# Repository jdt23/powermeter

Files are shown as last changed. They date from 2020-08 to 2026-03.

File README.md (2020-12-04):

# powerMeter
This project is a power meter for a bike that computes power, cadence, and resistance similar to a peloton bike.  For those of us who just have simple exercise bikes and a peloton digital subscription, this helps provide objective numbers to match to the instructors' cadence and resistance measurements.

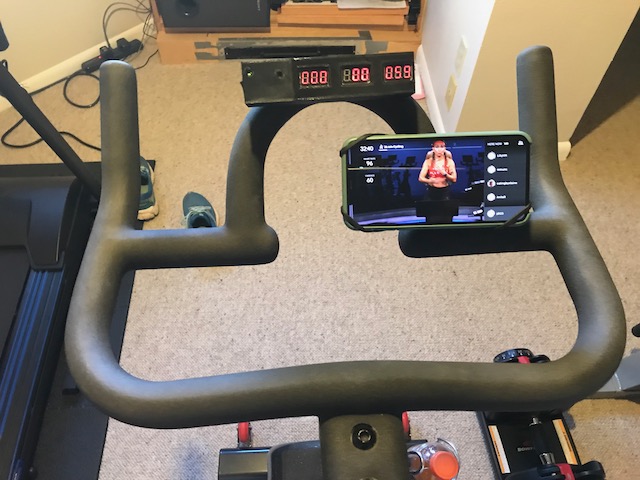
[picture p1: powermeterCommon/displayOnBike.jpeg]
display mounted on the bike handle bars

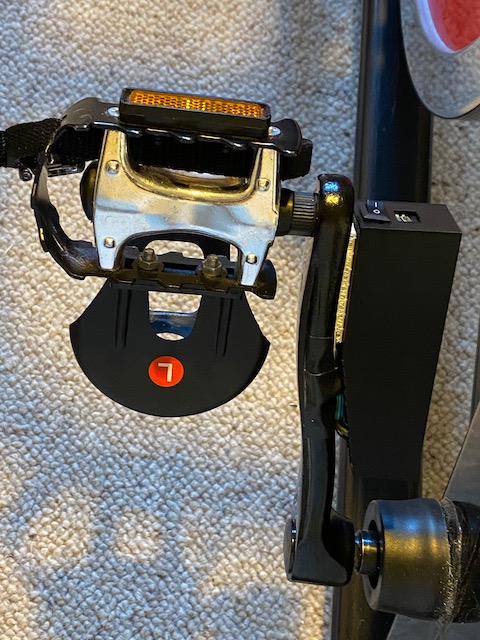
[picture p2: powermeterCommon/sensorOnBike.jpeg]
sensor mounted on bike crank


The solution I came up here uses a sensor unit attached to your bike crank, along with a display unit you attach to your handlebars.  The two units both use the [Arduino Nano 33 BLE](https://store.arduino.cc/usa/nano-33-ble) microprocessor.  For the sensor, the Nano 33 BLE is nice because it is tiny, it has an integrated IMU to give you a gyroscope for cadence, it has enough pins to interface with the force sensors, and it uses low power bluetooth 5.0.  For the display, it gets tight but has just enough GPIO ports for the cheap 7-segment LEDs I chose, and of course has bluetooth 5.0 to recieve the data from the sensor.  For powering both, I use 4x AAA rechargable batteries.

I also 3D-printed the cases for the sensor and display.

## powermeterSensor
This is the thing you attach to the bike crank. The key sensor here is the [HX711](https://smile.amazon.com/gp/product/B07MTYT95R) configured in a [wheatstone bridge](powermeterCommon/HX711_circuit.jpg).

### Algorithm
```
void setup() {
    set up bluetooth characteristics for read, notify
}
void loop() {
    read sensors
    compute new values
    if values change,
        write to bluetooth characteristics
}
```

### Power

Power meters measure the amount of force you exert on the bike crank.  This uses a strain gauge, similar to what is in a typical weight scale.  For some more background, take a look at [this student project](https://digitalcommons.calpoly.edu/cgi/viewcontent.cgi?article=1292&context=cpesp), which helped me get started.

#### Strain gauges

When a strain gauge is stressed, the resistance changes.  You can read the voltage across that resistor to detect the amount of change.  The problem is that this is a very noisy system, so people typically use a [Wheatstone Bridge](https://en.wikipedia.org/wiki/Wheatstone_bridge) circuit.

Wheatstone Bridge

In a Wheatstone Bridge such as the one in the figure above, you can apply a known voltage across A and C, then measure the output voltage across B and D.  If you apply 4 strain gauges on the bike crank in the right places, you can get it so an increase in resistance in R1 will also result in a reduction in resistance in R2, amplifying the change while introducing some redundancy (which is good).

I attached the strain gauges to bike crank with a very thin layer of superglue.

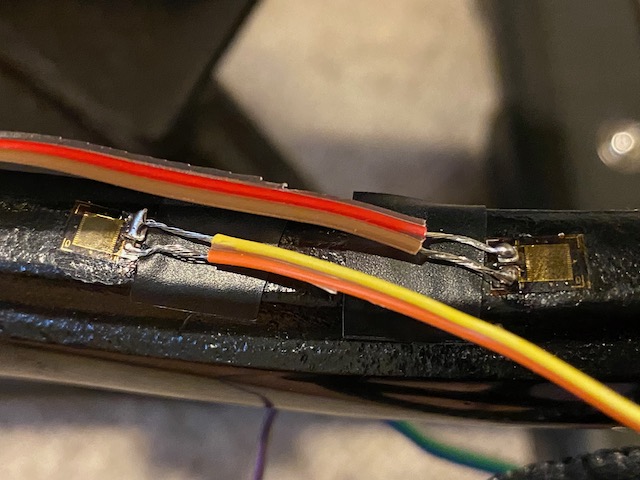
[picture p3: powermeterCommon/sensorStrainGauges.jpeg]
strain gauges


Using a bunch of electrical tape, I covered up all the wires and sensors on the bike crank, which ended up looking fairly clean.

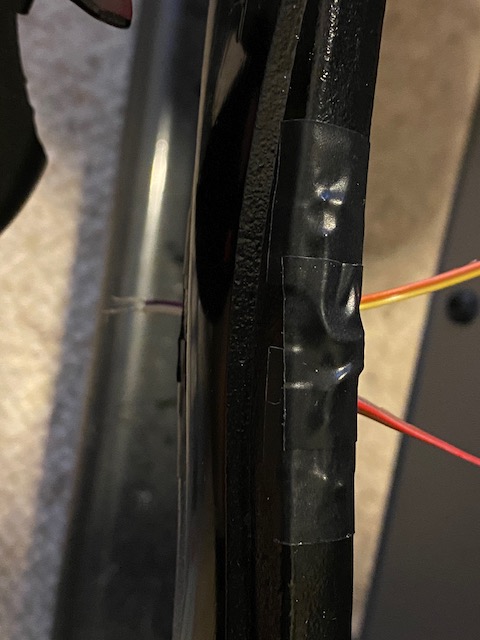
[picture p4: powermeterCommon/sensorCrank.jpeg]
bike crank


#### Amplifier

The resistance change from the strain gauges is still very small, so we need to amplify it.  To do that, most people use an [HX711](https://cdn.sparkfun.com/datasheets/Sensors/ForceFlex/hx711_english.pdf) circuit such as the one below.

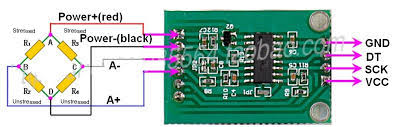
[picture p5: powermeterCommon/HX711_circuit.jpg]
hx711 image


This circuit is fairly easy to use, cheap, and has a well supported [library](https://github.com/bogde/HX711) to simplify usage.

#### Computing Force

The instantaneous power of an angularly accelerating body is the torque (tau) times the angular velocity (omega).



Tau is just Force x Distance, so we get:



We'll get the force from the HX711, after calibrating and scaling.  r is the radius of the bike crank.  Angular velocity here is expected in radians/second, and the Arduino gives it to you in degrees/second, so we have to remember to multiply by a scale factor.  2pi radians is 360 degrees, so you multiply your dps by pi/180



Done.  

I skipped over calibrating and scaling the readings off the HX711, but it's relatively straightforward.  I assume zero weight when turning on the sensor, and use the first few seconds to read the neutral scale reading. That becomes the offset you pass to the `scale.set_offset()` function.  Then, I put a known weight (5 lbs in my case) on the pedal, and read the scale.  Each pound is 4.448 Newtons, so I set the scale factor to the reading divided by the weight I used times 4.448



### Resistance

Now this is the hard part.  Peloton listed official (Power,Resistance,Cadence) triples [here](https://www.reddit.com/r/pelotoncycle/wiki/index/faq/bikecalibration).  A nice user put those datapoints into a regression script and came up with equations [here](https://www.reddit.com/r/pelotoncycle/comments/gwpyfw/diy_peloton_resistance_output/):

![](https://latex.codecogs.com/svg.latex?\Large&space;r=145\left(\frac{Power}{11.29(Cadence-22.5)^{1.25}}\right)^{0.4651})

I plotted the sample points and verified the equations seem to work in [this script](./powermeterCommon/calibrate.py).

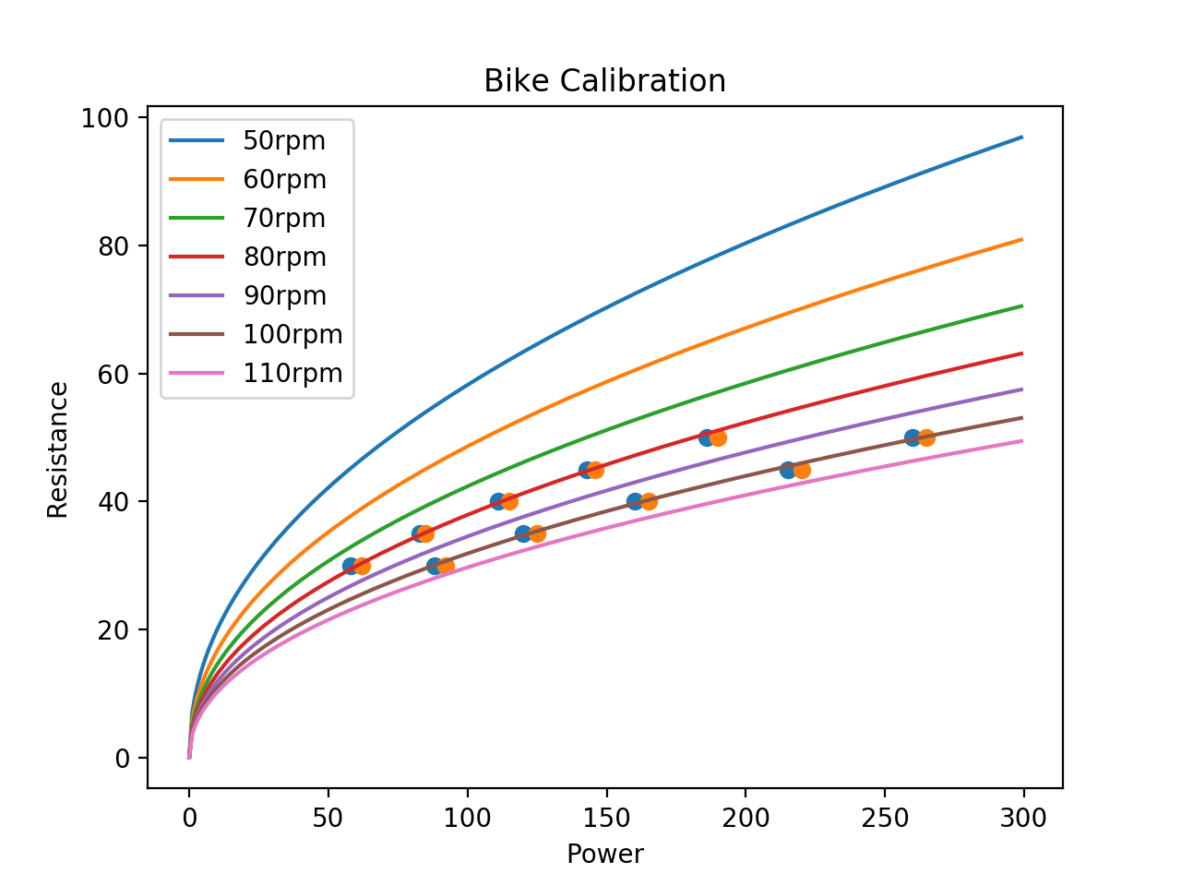
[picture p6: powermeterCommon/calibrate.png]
plot of known datapoints and equations


So I just plugged in those equations, fixed up for cases where it would fall below zero and produce NaNs, and boom, done.

### Cadence

Cadence is easily sensed using the IMU on the Nano 33 BLE.  There's a simple `readGyroscope()` API.  You grab the z direction of that, and convert from degrees per second to revolutions per minute.

In full disclosure, I had to multiply the cadence by (7/6) for some reason I haven't figured out yet.  Doing this, I exactly match the wahoo cadence sensor I already had.  Some day I should try to fix this, but if you know why I might be off by 7/6, please let me know.

### Power supply

A key requirement is to have a power supply that is cabable of providing sustained current.  I initially started with some button batteries, but those would only last about 10 minutes before they started giving bogus numbers as a result of insufficient voltage to the chip.  Because of that, I moved to using 4xAAA rechargeable batteries.  This makes the cases slightly larger, but I believe they're still reasonably sized.

### Measurements

Any measurement is going to have some noise to it.  To add some hysteresis, I created a `Measurement` struct that can take a `refreshInterval` (in milliseconds) and a way to reduce the results either via averaging or taking the max of a bunch of samples.  

In practice, I settled on about 2 seconds of samples, which ended up being about 20 samples.  For power, I expected to have to use max, but ended up using averaging, similar to cadence and resistance.

### Sensor board and case

For the circuit board, I used a 2cm x 8cm prototype [circuit board](https://smile.amazon.com/gp/product/B072Z7Y19F). That wasn't quite wide enough for the Arduino Nano, so I ended up only using pins on one side of the board, and snipped the headers on the other side so the whole Arduino still laid flat.  I did some clever wiring under the Arduino on the top side of the prototype board, which minimized the wiring underneath.  Next to the Arduino is the HX711, with the input pins soldered to 4 outward facing pins that I would attach the bike to.

Here is the fritzing image of the circuit.

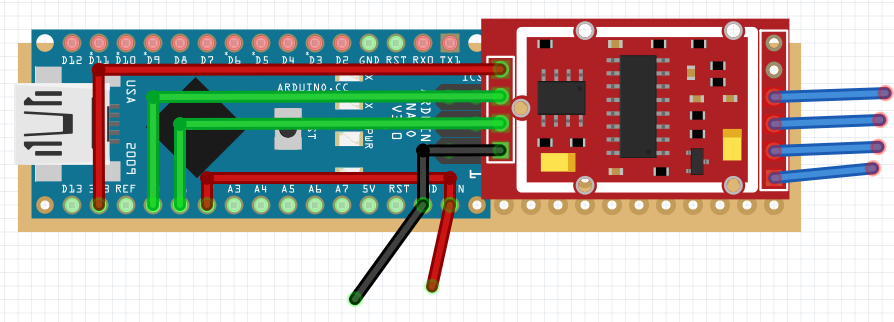
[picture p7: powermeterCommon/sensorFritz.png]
sensor circuit board fritz


And here is the same thing in real life.

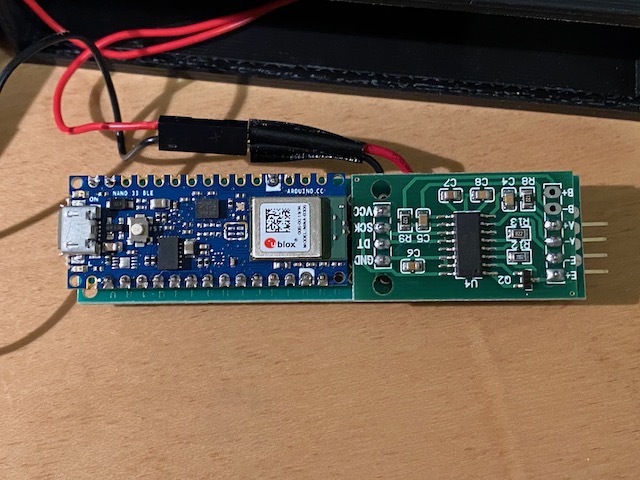
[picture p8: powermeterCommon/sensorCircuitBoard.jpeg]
sensor circuit board


This is a picture of the batteries in the case.

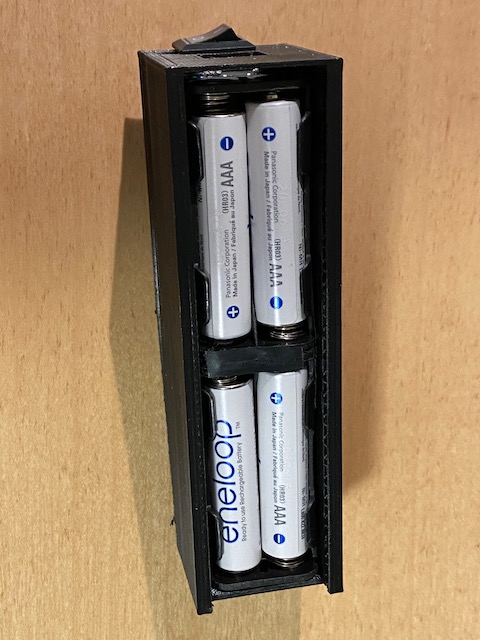
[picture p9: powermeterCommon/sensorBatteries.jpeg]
sensor batteries


And finally, this is the case that I 3D printed for it.

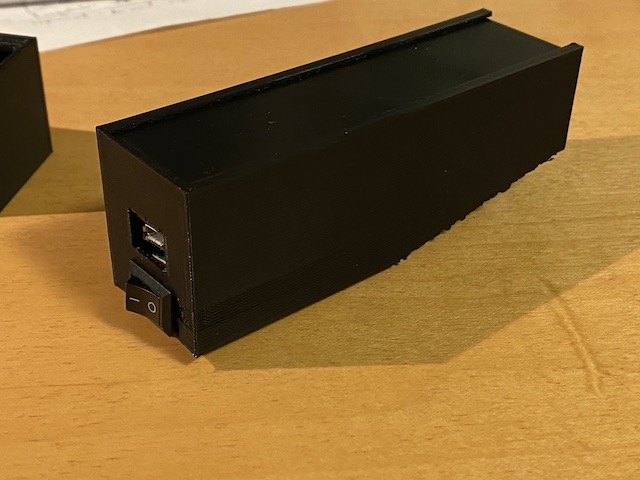
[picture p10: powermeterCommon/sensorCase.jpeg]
sensor case


## powermeterDisplay

You could display the results on your phone, or another type of display.  For my bike, I wanted to play with some seven segment displays, so I got three [three-digit seven segment displays](https://smile.amazon.com/gp/product/B07GTQS4N5).

Pseudo-code is:
```
void setup() {
    set up bluetooth
}

void loop() {
    connect to bluetooth
    while connected to bluetooth{
        subscribe to notifications
        if values updated
            read values
        display
    }
}
```

### 7 segment displays

I bought [cheap 3 digit 7 segment displays](https://smile.amazon.com/gp/product/B07GTQS4N5/) (non-I2C) so it took a lot of the GPIO pins to drive.  This took a lot of wiring.

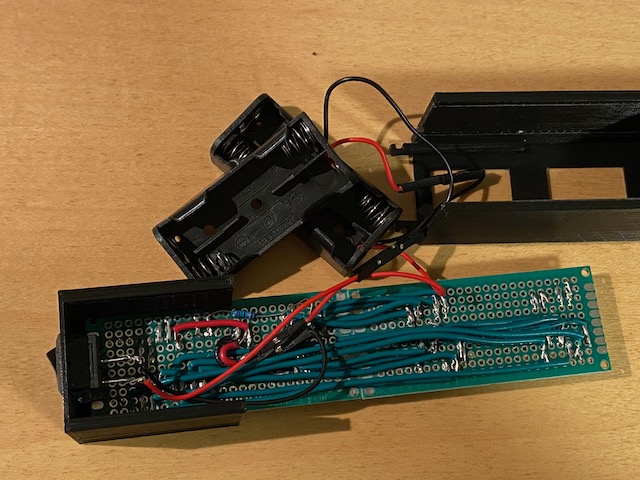
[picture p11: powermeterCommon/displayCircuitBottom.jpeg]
wiring


### Power supply

Just like the sensor, I had some issues with sustained voltage for the display.  I resorted to the same solution for the display, 4x AAA batteries.  For the display, it just extends the height of the case, so it's not a big deal.

### Display Board and Case

For the display, I used two of the 2cm x 8xm prototype boards, taped together.  This perfectly allows room for the Arduino and three 3-digit displays.  The wiring gets tight, but some careful planning solved that.

Here is the circuit board fritz on a much larger PCB.  Converting this to something that all fit in the 2cm x 8cm prototype board took a lot of planning, and using both the top and bottom side of the board.

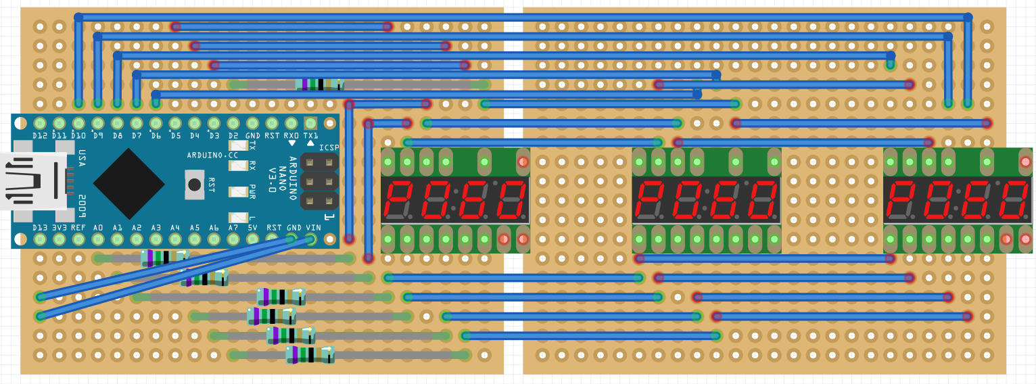
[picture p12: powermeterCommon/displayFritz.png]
display circuit board fritz


And here's a picture of the same thing in real life:

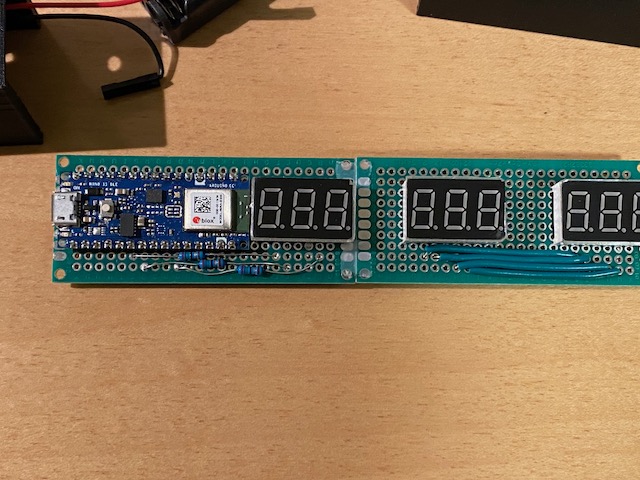
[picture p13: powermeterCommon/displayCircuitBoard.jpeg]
display circuit board


Here's the final case I settled on, after about 10 attempts.

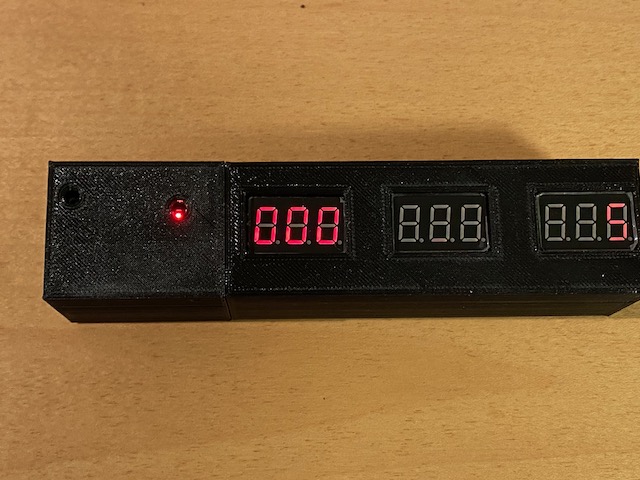
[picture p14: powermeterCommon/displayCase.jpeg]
display case


## Bill of Materials

| Part | Cost Total | Cost for this project |
| ---- | --- | --- |
| [Arduino Nano 33 BLE](https://smile.amazon.com/gp/product/B07WV59YTZ/) | $23.00 each | 2 for $46.00 |
| [LED Displays](https://smile.amazon.com/gp/product/B07GTQS4N5) | $8.59 for 5 | 3 for $5.16 |
| [PCB boards](https://smile.amazon.com/gp/product/B072Z7Y19F) | $9.99 for 32 | 3 for $0.94 |
| [Rocker Switches](https://smile.amazon.com/gp/product/B07JNNXC9N) | $6.99 for 20 | 2 for $0.70 |
| [Battery cases](https://smile.amazon.com/gp/product/B07F3YKGPD) | $4.99 for 6 | 4 for $3.33 |
| [Rechargeable AAA batteries](https://smile.amazon.com/gp/product/B00JHKSMIG) | $16.57 for 8 | 8 for $16.57 |
| [Strain Gauges](https://smile.amazon.com/gp/product/B085W5KSSD) | $4.75 for 10 | 4 for $1.90 |
| [HX711 Load Cell Amplifiers](https://smile.amazon.com/gp/product/B07MTYT95R) | $6.99 for 5 | 1 for $1.40 |
| Total | $104.87 | $76.00 |

Some things, I already had, such as a soldering iron, multimeter, wiring, wire strippers, crimpers, 3d printer with filament, etc, so I'm not including the cost of those.  But for someone new, your upfront costs might be more.

So for $76 plus about $30 of extra parts, I have a power, resistance, and cadence meter.  If I [google for power meters](https://lmgtfy.app/?q=power+meter) alone, the cheapest one I see is about $300, and they get much more expensive than that quickly.  Maybe you already have batteries.

## Future work

I haven't looked at current draw yet.  If the batteries start draining too quickly, I'll have to look at that and likely just sleep longer between sampling and transmitting.

I'd also like to figure out the mysterious (7/6) factor for the cadence.

I could probably also spend more time calibrating the power, but the whole point is that it's an objective measure.  For that, I think the current numbers serve the purpose.

Hope you've enjoyed.  If you end up building something similar, or have any advice, feel free to reach out.

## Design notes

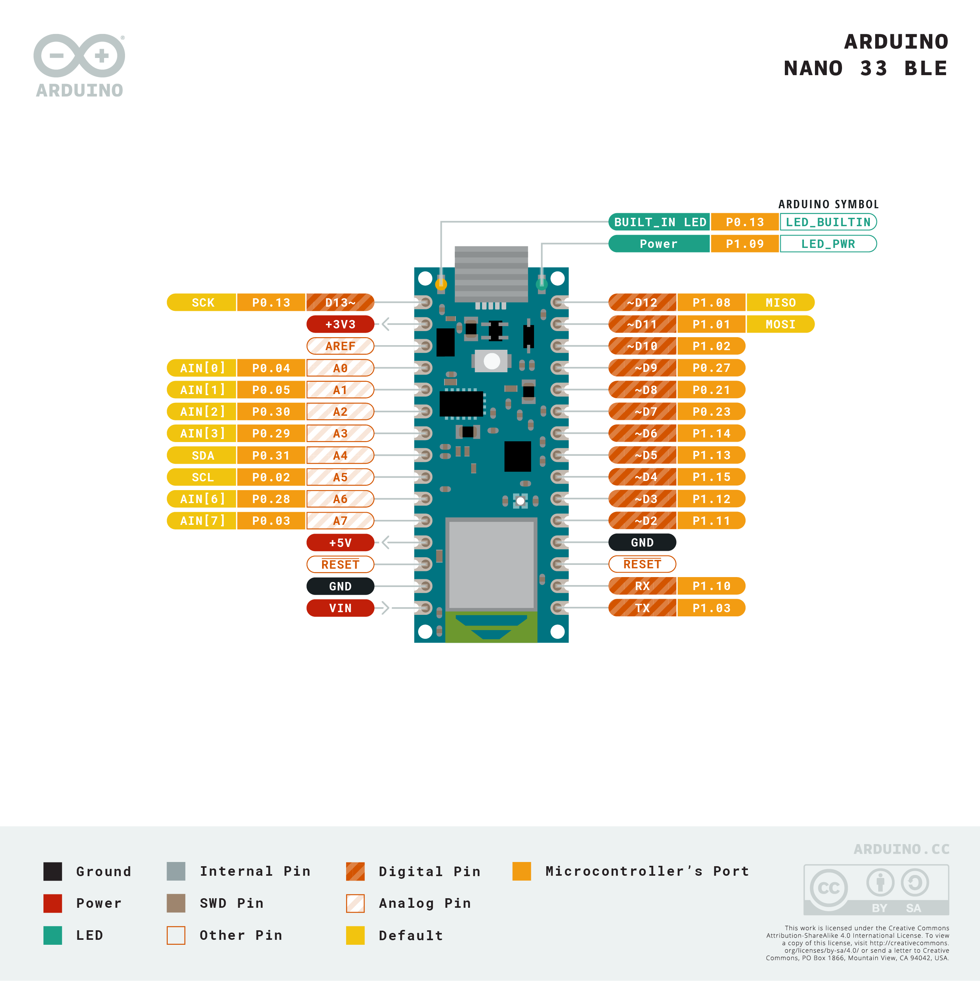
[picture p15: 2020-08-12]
powermeterCommon/nano33ble_pinout.png

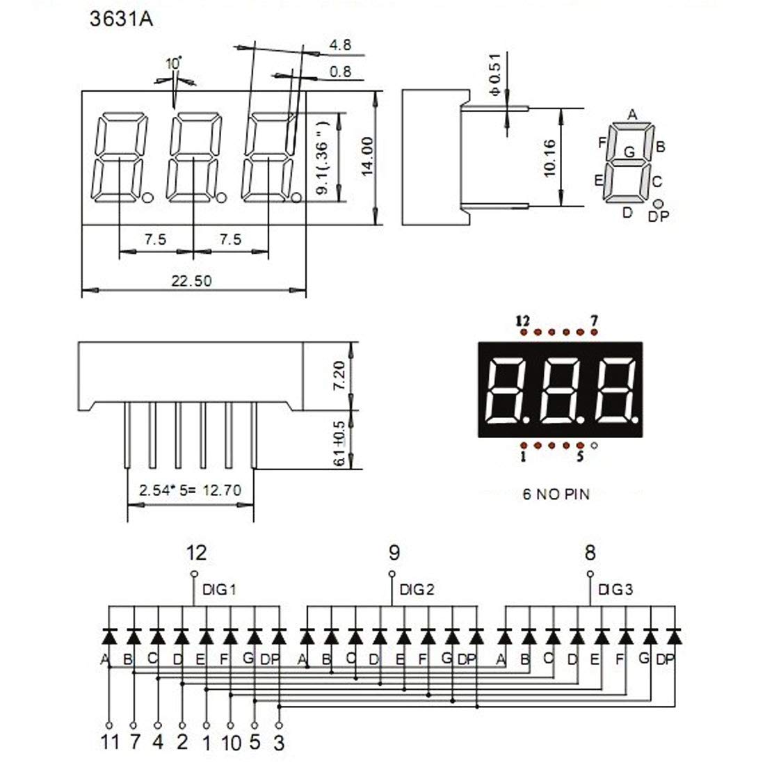
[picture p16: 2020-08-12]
powermeterCommon/3631AH_pins.jpg

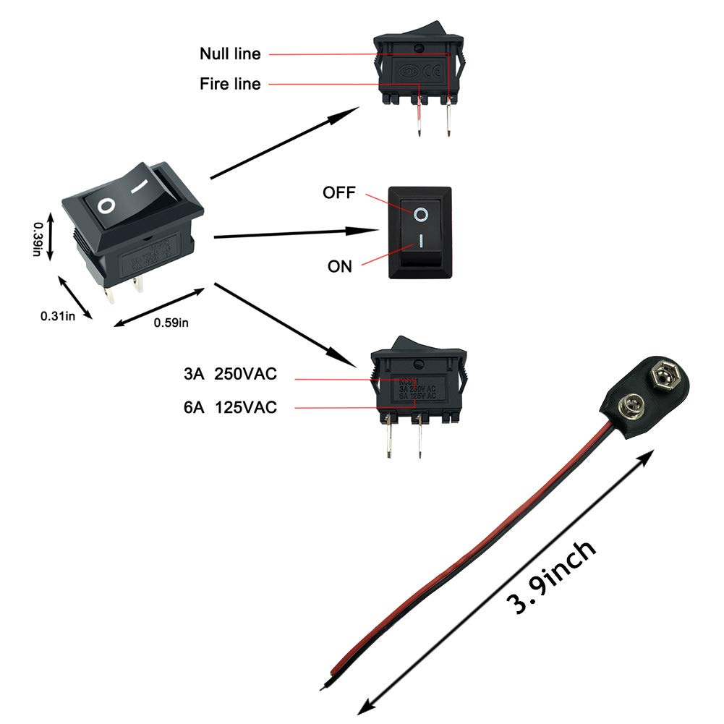
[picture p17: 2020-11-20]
powermeterCommon/rocker_switch.jpg

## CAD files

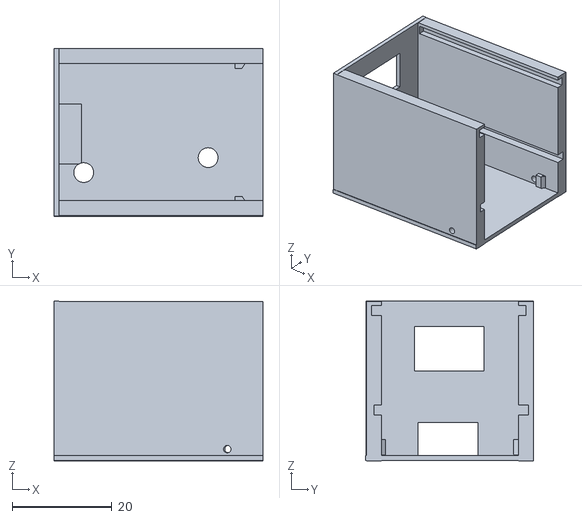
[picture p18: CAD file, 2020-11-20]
powermeterDisplay/case/powermeterDisplay_prototype7_topleft.stl
42.0 x 33.7 x 32.1

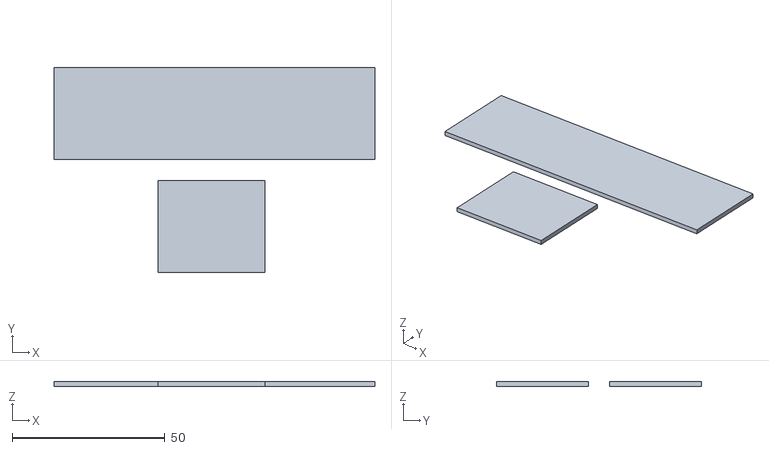
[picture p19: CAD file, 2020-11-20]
powermeterDisplay/case/powermeterDisplay_prototype7_bottoms.stl
105.0 x 67.0 x 1.50

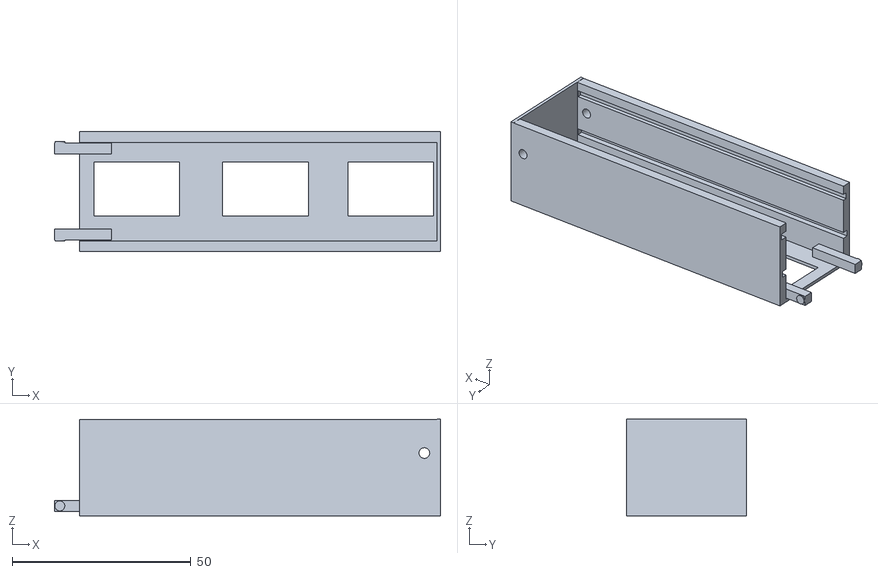
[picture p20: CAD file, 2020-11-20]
powermeterDisplay/case/powermeterDisplay_prototype6_top_right.stl
108.0 x 33.6 x 27.1

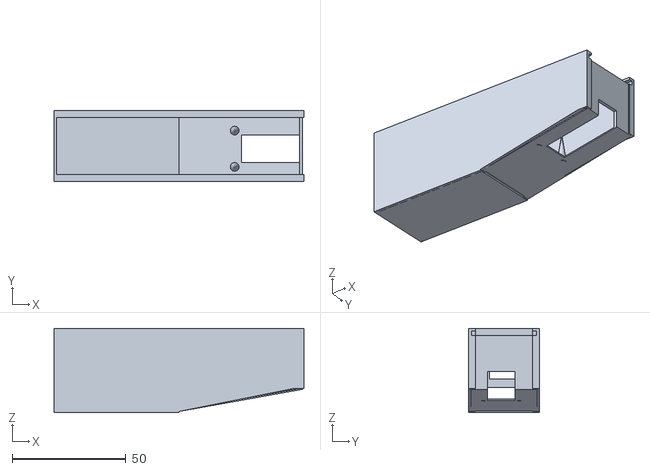
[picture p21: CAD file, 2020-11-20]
powermeterSensor/case/powermeterSensor_prototype4_bottom.stl
110.1 x 31.2 x 37.1

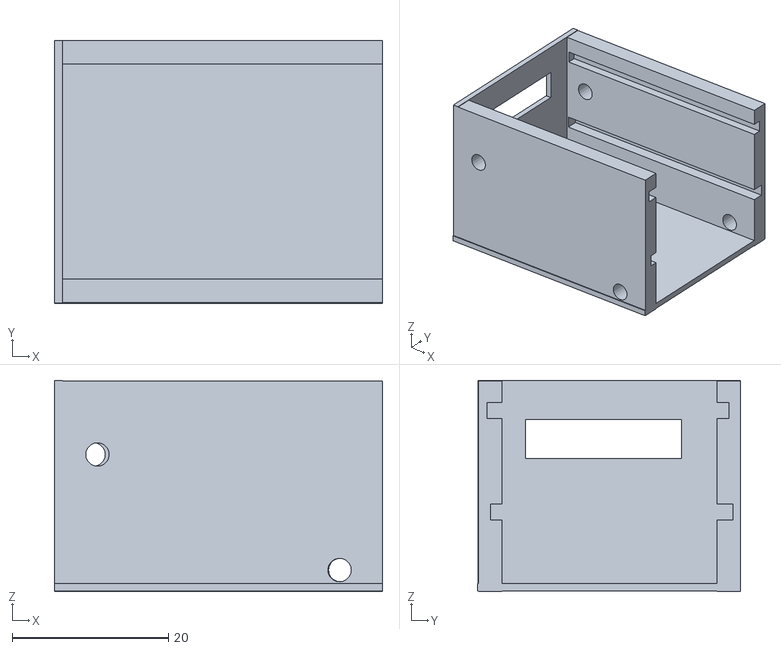
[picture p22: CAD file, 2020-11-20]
powermeterDisplay/case/powermeterDisplay_prototype6_top_left.stl
42.0 x 33.7 x 27.1

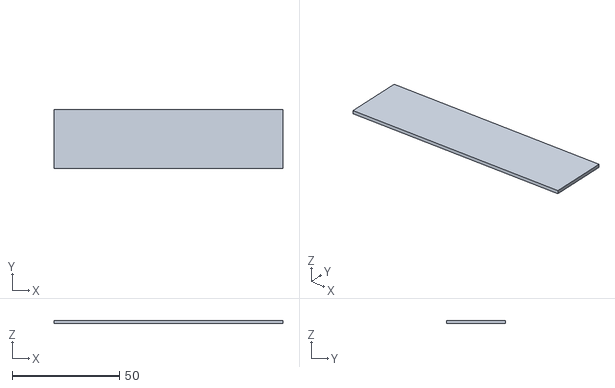
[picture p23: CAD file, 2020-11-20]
powermeterSensor/case/powermeterSensor_prototype4_top.stl
107.0 x 27.5 x 1.50

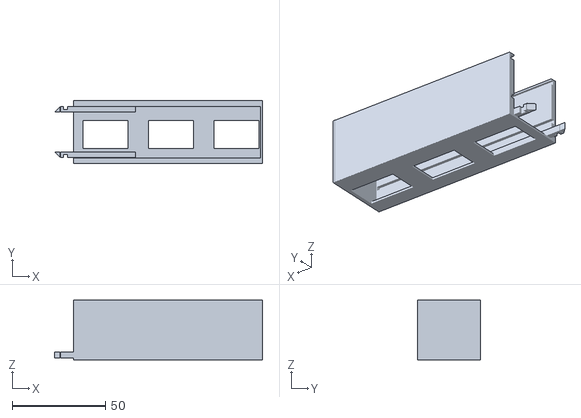
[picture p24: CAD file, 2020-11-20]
powermeterDisplay/case/powermeterDisplay_prototype7_topright.stl
111.3 x 33.6 x 32.1

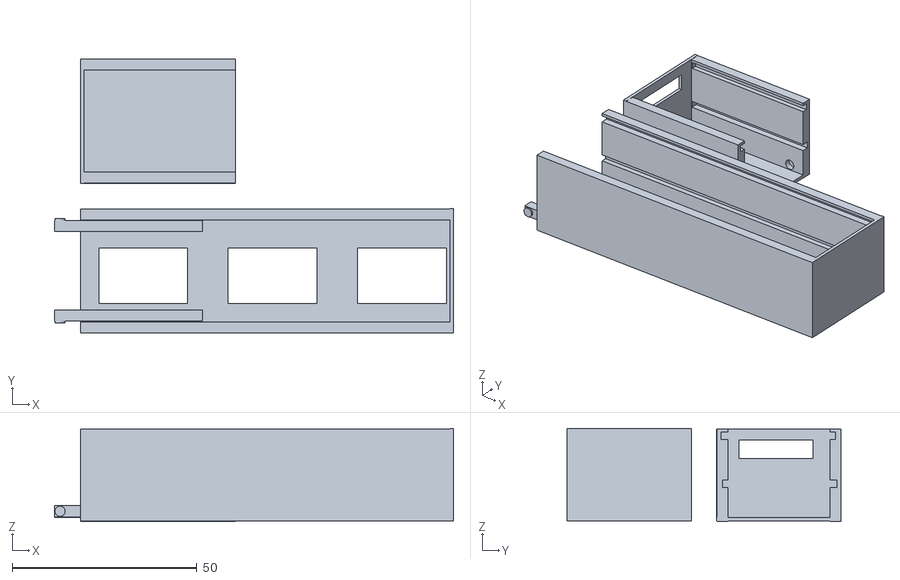
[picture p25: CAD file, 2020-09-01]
powermeterDisplay/case/powermeterDisplay_prototype6_top.stl
108.0 x 74.1 x 25.2

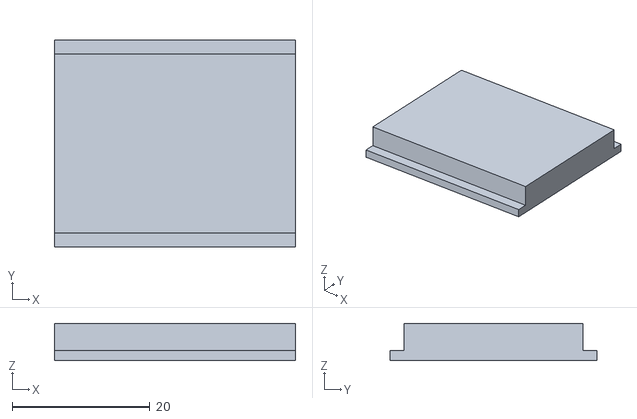
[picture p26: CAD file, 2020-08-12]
powermeterDisplay/case/powermeterDisplay_prototype5_bottomright.stl
35.0 x 30.0 x 5.40

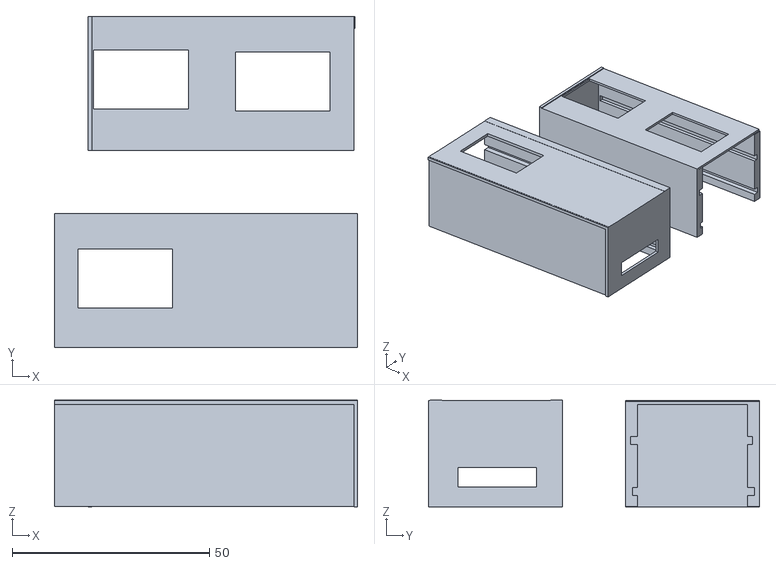
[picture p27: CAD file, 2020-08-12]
powermeterDisplay/case/powermeterDisplay_prototype4_tops.stl
77.0 x 84.0 x 27.1

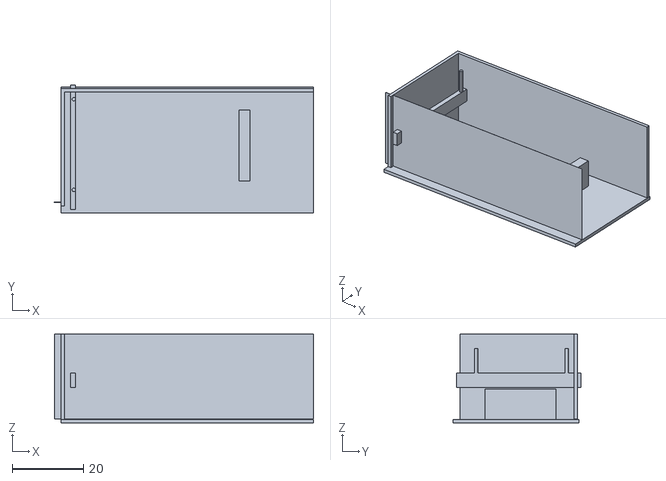
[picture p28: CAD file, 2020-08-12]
powermeterDisplay/case/lefthalf.stl
72.8 x 36.0 x 25.0

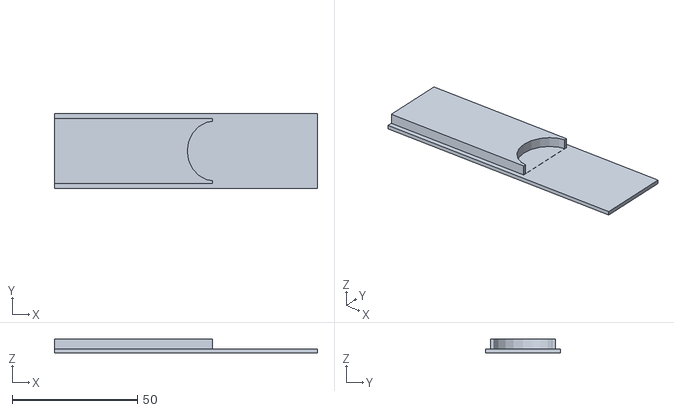
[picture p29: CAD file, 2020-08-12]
powermeterDisplay/case/powermeterDisplay_prototype5_bottomleft.stl
105.0 x 30.0 x 5.40

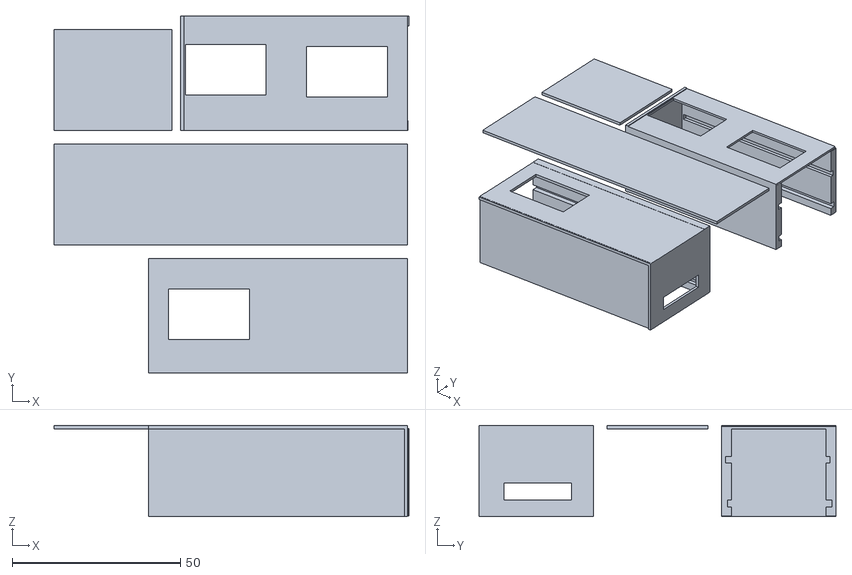
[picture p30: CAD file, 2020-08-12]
powermeterDisplay/case/powermeterDisplay_prototype4.stl
105.4 x 106.0 x 27.1

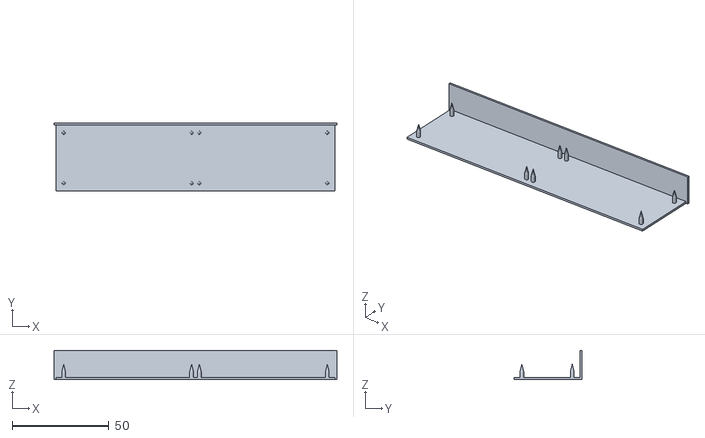
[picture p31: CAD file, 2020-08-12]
powermeterDisplay/case/powermeterPeripheral_LCD.stl
146.0 x 35.0 x 15.0

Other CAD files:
powermeterSensor/case/powermeterSensor_prototype3_bottom.stl
powermeterSensor/case/powermeterSensor_prototype3_top.stl
powermeterSensor/case/powermeterSensor_prototype2_bottom.stl
powermeterSensor/case/powermeterSensor_prototype1_top.stl
powermeterDisplay/case/powermeterDisplay_prototype1.stl
powermeterDisplay/case/powermeterDisplay_prototype2_bottoms.stl
powermeterDisplay/case/powermeterDisplay_prototype2_tops.stl
powermeterDisplay/case/powermeterDisplay_prototype3.stl
powermeterDisplay/case/powermeterDisplay_prototype4_bottoms.stl
powermeterDisplay/case/powermeterDisplay_prototype4_topleft.stl
powermeterDisplay/case/powermeterDisplay_prototype4_topright.stl
powermeterDisplay/case/powermeterDisplay_prototype5_bottoms.stl
powermeterDisplay/case/powermeterDisplay_prototype5_topright.stl
powermeterSensor/case/powermeterSensor_prototype1_bottom.stl
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

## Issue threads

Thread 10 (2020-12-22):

Investigate power consumption

jdt23, 2020-12-22:
Of both the display and the sensor.

One likely culprit is the display - I expect the SevSeg library is refreshing too often.

The sensor is already fairly optimized to not push changes to bluetooth unless needed, so I don't expect much there, but it's definitely possible.

So far, battery life has not been horrible, so not urgent.

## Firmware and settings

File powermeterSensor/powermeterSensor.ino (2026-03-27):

// HX711 Arduino Library - Version: Latest
// For strain gauges
#include <HX711.h>

// ArduinoBLE - Version: Latest
// For bluetooth
#include <ArduinoBLE.h>

BLEService powerMeterService("1818");
// Standard Cycling Power Measurement: 4 bytes (2 flags + 2 power)
BLECharacteristic powerChar("2A63", BLERead | BLENotify, 4);
BLEUnsignedCharCharacteristic  resistanceChar("2AD6", BLERead | BLENotify );
BLEUnsignedCharCharacteristic  cadenceChar("2A5B", BLERead | BLENotify );

// Arduino_LSM9DS1 - Version: Latest
// For IMU
#include <Arduino_LSM9DS1.h>

const float Radius = 0.17; //meters

int counter = 0;

const int DEBUG = 0;

// HX711 circuit wiring
const int LOADCELL_DOUT_PIN = A1;
const int LOADCELL_SCK_PIN = A0;

HX711 scale;
float accelerationSampleRate, gyroscopeSampleRate;

const int BATTERY_PIN = A2;

enum MeasurementMethod {AVERAGE, MAX, NONE};

struct Measurement {
  float accumulator;
  int samples;
  unsigned long last_time;
  unsigned long next_time;
  unsigned int refreshInterval; // in milliseconds
  MeasurementMethod method;

  Measurement(const unsigned int _refreshInterval, MeasurementMethod _method) :
    accumulator(0),
    samples(0),
    last_time(0),
    next_time(0),
    refreshInterval(_refreshInterval),
    method(_method)
    {}
  void reset() {
    accumulator = 0;
    samples = 0;
    last_time = millis();
    next_time = last_time + refreshInterval;
  }
  void addMeasurement(float a) {
    if (method==AVERAGE)
      accumulator += a;
    else if (method == MAX)
      accumulator = fmaxf(a, accumulator);
    samples++;
  }
  bool canGetMeasurement() {
    return (millis() > next_time);
  }
  float getMeasurement() {
    if (DEBUG) {
      Serial.print("accumulator=");
      Serial.print(accumulator);
      Serial.print(" samples=");
      Serial.println(samples);
    }
    if (samples == 0)
      return NAN;
    float retval = NAN;
    if (method==AVERAGE)
      retval= accumulator / samples;
    else if (method==MAX)
      retval = accumulator;
    reset();
    return retval;
  }
};
Measurement powerMeasurement(2000, AVERAGE);
Measurement resistanceMeasurement(2000, AVERAGE);
Measurement cadenceMeasurement(2000, AVERAGE);

void setLED (int r, int g, int b) {
  digitalWrite(LEDR, 1-r);
  digitalWrite(LEDG, 1-g);
  digitalWrite(LEDB, 1-b);
}

void setup() {
  if (DEBUG) Serial.begin(9600);
  //HX711 setup
  scale.begin(LOADCELL_DOUT_PIN, LOADCELL_SCK_PIN);
  //scale.set_offset(1);
  if (DEBUG) Serial.println("Calibrating scale.");
  float offset = scale.get_units(20);
  offset = scale.get_units(10);
  if (DEBUG) Serial.print("Setting offset to ");
  if (DEBUG) Serial.println(offset);
  scale.set_offset(offset);
  //scale.set_offset(136200);
  // 1 pound = 4.4482216153 Newtons
  // scale factor = reading / (N) = reading / (lbs * 4.4482216153)
  //scale.set_scale(1);
  scale.set_scale(5000/ (5 * 4.4482216153));

  // initialize digital pin LED_BUILTIN as an output.
  pinMode(LED_BUILTIN, OUTPUT);
  pinMode(LEDR, OUTPUT);
  pinMode(LEDG, OUTPUT);
  pinMode(LEDB, OUTPUT);

  setLED(0,0,1);

  //IMU setup
  while (!IMU.begin()) {
    if (DEBUG) Serial.println("Failed to initialize IMU!");
    setLED(1,1,0); // yellow
    delay(1000);
  }

  accelerationSampleRate = IMU.accelerationSampleRate();
  gyroscopeSampleRate    = IMU.gyroscopeSampleRate();

  //bluetooth setup
  while ( !BLE.begin() ) {
    if (DEBUG) Serial.println("starting BLE failed!");
    setLED(1,1,1); // white
    delay(1000);
  }
  if (DEBUG) Serial.println ("Bluetooth startup succeeded");

  BLE.setLocalName("powerMeterService");
  BLE.setAdvertisedService(powerMeterService);
  powerMeterService.addCharacteristic(powerChar);
  powerMeterService.addCharacteristic(resistanceChar);
  powerMeterService.addCharacteristic(cadenceChar);
  BLE.addService(powerMeterService);

  BLE.advertise();
  if (DEBUG) Serial.println("Bluetooth device active, waiting for connections...");
}

float computeResistance ( const float &power, const float &rpm ) {

  // https://www.reddit.com/r/pelotoncycle/comments/gwpyfw/diy_peloton_resistance_output/
  //  $Resistance = (145*($Power/(11.29*($Cadence-22.5)^1.25))^(.4651))
  float r = (145*pow(power/(11.29f*pow(max( (rpm-22.5f),1 ),1.25f)),(0.4651)));

  // https://www.reddit.com/r/pelotoncycle/wiki/index/faq/bikecalibration

  // https://www.reddit.com/r/pelotoncycle/comments/b0bulz/how_the_peloton_bike_calculates_output_and_speed/
  // Output ~= (Cadence - 35) * (Resistance/100)2.5 * 24
  // Speed ~= (Cadence - 35)0.4 * (Resistance/100) * 9 + 0.4
  // Output ~= Speed2.5 / 10

  // Output ~= (Cadence - 35) * (Resistance/100)2.5 * 24
  // (Resistance/100)2.5 = Output / (24 * (Cadence-35))
  // Resistance = 100 * Output / (2.5*24*(cadence-35))
  //float r = 5 * power / (3 * (rpm - 35));

  if (DEBUG) {
    Serial.print("computing resistance: p  =");  Serial.println(power);
    Serial.print("computing resistance: rpm=");  Serial.println(rpm);
    Serial.print("computing resistance: r  =");  Serial.println(r);
  }
  return fmaxf(r,0);
}

unsigned short float2ushort (const float &val, const char * name, const float & maxval) {
  unsigned short val_uchar = (unsigned short)fabsf(val+0.5f);// 0.5 for rounding
  if (DEBUG) {
    Serial.print(name);
    Serial.print("=");
    Serial.print(val_uchar);
    Serial.print(",");
    Serial.print(val);
    Serial.print("\t");
  }
  return min(val_uchar, maxval);
}

unsigned char float2uchar (const float &val, const char * name, const float & maxval) {
  unsigned char val_uchar = (unsigned char)fabsf(val+0.5f);// 0.5 for rounding
  if (DEBUG) {
    Serial.print(name);
    Serial.print("=");
    Serial.print(val_uchar);
    Serial.print(",");
    Serial.print(val);
    Serial.print("\t");
  }
  return min(val_uchar, maxval);
}

void loop() {

  setLED(1,0,0); // red
  delay(100);

  //bluetooth stuff
  BLEDevice central = BLE.central();

  if (central || DEBUG) {
    setLED(1,1,0); // yellow means central active but not connected yet

    if (DEBUG) Serial.print("Connected to central: ");
    if (DEBUG) Serial.print(central.address());

    unsigned short power_short=0, power_short_new=0;
    unsigned char  resistance_char=0, resistance_char_new=0;
    unsigned char  cadence_char=0, cadence_char_new=0;

    while (central.connected() || DEBUG) {
      setLED(0,0,0); // turn leds off while connected

      if (DEBUG) Serial.print("\nCounter = ");
      if (DEBUG) Serial.print(counter++);

      // to measure cadence, the gyroscope Z dimension tells you degrees/second
      // which can easily be converted to RPM
      float gyro_x, gyro_y, gyro_z = 0;
      if (IMU.gyroscopeAvailable()) {
        IMU.readGyroscope(gyro_x, gyro_y, gyro_z);

        if (DEBUG) {
          Serial.print("\tGyro=\t");
          Serial.print(gyro_x);
          Serial.print('\t');
          Serial.print(gyro_y);
          Serial.print('\t');
          Serial.print(gyro_z);
        }
      } else {
        if (DEBUG) Serial.print("gyro not available\t");
      }
      if (DEBUG) Serial.print("\t");

      // gyro_X is in degrees/second.  one revolution is 360 degrees.
      // rev/min = (deg/sec) * (60sec/1min) * (1rev/360deg)
      // rev/min = (deg/sec) * (1/6)
      //float angular_velocity = sqrtf(gyro_x*gyro_x + gyro_y*gyro_y + gyro_z*gyro_z);
      float angular_velocity = fabsf(gyro_z); // this is what it used to be, when i needed the 1.15x
      float new_cadence = (angular_velocity) / 6.0f;
      // HACK: not sure why we need to multiply by (7/6), but doing this matches my wahoo meter.
      new_cadence *= (7/6);
      cadenceMeasurement.addMeasurement(new_cadence);

      /* Get values from the strain gauges */
      float reading = scale.get_units(1);
      if (DEBUG) {
        Serial.print("Scale Reading:\t"); Serial.println(reading);
      }
      // scale gives you force in newtons
      // Force_in_Newtons * angular velocity = instantaneous power
      // power (Newton-meter) = torque (radius(m)*Force*())* angular_velocity (in rad/sec)
      //   angular_velocity should be in radians/second
      //   rad/sec = (deg/sec) * (3.14159/180)(rad/deg)
      // 1Watt = 1Newton-meter per second
      float new_power = fabsf( Radius * fabsf(reading) * angular_velocity * 3.1415926535 / 180 );
      // HACK: divide power by 2. hand wave something about measuring power on one of two pedals
      new_power /= 2.0f;
      powerMeasurement.addMeasurement(new_power);

      // get new measurements if it's time to
      if (powerMeasurement.canGetMeasurement()) {
        power_short_new = float2ushort(powerMeasurement.getMeasurement(), "Power", 999);
      }
      // only write new values if needed
      if (power_short_new != power_short) {
        power_short = power_short_new;
        // Standard Cycling Power Measurement format:
        // Bytes 0-1: Flags (0x0000 = no optional fields)
        // Bytes 2-3: Instantaneous Power (sint16, little-endian)
        uint8_t powerData[4];
        powerData[0] = 0x00; // flags low byte
        powerData[1] = 0x00; // flags high byte
        powerData[2] = (uint8_t)(power_short & 0xFF);       // power low byte
        powerData[3] = (uint8_t)((power_short >> 8) & 0xFF); // power high byte
        powerChar.writeValue(powerData, 4);
      }

      if (cadenceMeasurement.canGetMeasurement()) {
        cadence_char_new = float2uchar(cadenceMeasurement.getMeasurement(), "Cadence", 250);
      }
      if (cadence_char_new != cadence_char) {
        cadence_char = cadence_char_new;
        cadenceChar.writeValue(cadence_char);
      }

      float new_resistance = computeResistance(power_short, cadence_char);
      resistanceMeasurement.addMeasurement(new_resistance);
      if (resistanceMeasurement.canGetMeasurement()) {
        resistance_char_new = float2uchar(resistanceMeasurement.getMeasurement(), "Resistance", 99);
      }
      if (resistance_char_new != resistance_char) {
        resistance_char = resistance_char_new;
        resistanceChar.writeValue(resistance_char);
      }

      // add delay to prevent values from changing too quickly
      delay(100);
    }
    setLED(1,1,0); // yellow should only be on temporarily

  }
  setLED(1,0,0); // red means not connected
  delay(1000); // wait a second if not connected

  if (DEBUG) {
    int battery = analogRead(BATTERY_PIN);
    int batteryLevel = map(battery, 0, 1023, 0, 100);
    Serial.print("Battery: ");
    Serial.print(batteryLevel);
    Serial.println("\%");
  }

  //Serial.println("");
  return;

}

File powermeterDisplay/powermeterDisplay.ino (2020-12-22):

// make sure to set MAXNUMDIGITS to 9 in your local copy. Default is 8 digits
// and defining it here doesn't seem to work
#include <SevSeg.h>
SevSeg sevseg;

#include <ArduinoBLE.h>

int counter = 0;

const int DEBUG = 0;

const int BATTERY_PIN = A4;

// inputs are binary ints. either 0 or 1.
// but need to invert from the way I expect since high is off and low is on
void setLED (int r, int g, int b) {
  digitalWrite(LEDR, 1-r);
  digitalWrite(LEDG, 1-g);
  digitalWrite(LEDB, 1-b);
}

// not using this function yet, as it screws up timing for the digits. 
void removeLeadingZeros(int val, int hundredsPin, int tensPin) {
  // common cathode, so HIGH is off
  if (val < 100) {
    digitalWrite(hundredsPin, HIGH);
  }
  if (val < 10) {
    digitalWrite(tensPin, HIGH);
  }
}

void displayPowerResistanceCadence (int power, int resistance, int cadence) {
  /*
   * Product Name: LED Digital Display Tube; 
   * Type: Common Cathode; Model: 3631AH
   * Common Cathode: 12-9-8; Digital Display: 3 Digit; Digital Number: 3 Bit 7 Segment; Emitted Color: Red
   * Pin Number: 11; Continuous Forward Current: 20mA; Average Forward Voltage: 2V; Power Consumption: 36mW
   */

  sevseg.setNumber(1000000*power + 1000*resistance + cadence);
//  removeLeadingZeros(power, 3, 4);
//  removeLeadingZeros(resistance, 11, 6);
//  removeLeadingZeros(cadence, 8, 9);
  sevseg.refreshDisplay();
}

void setup() {
  if (DEBUG) Serial.begin(9600);

  // initialize digital pin LED_BUILTIN as an output.
  pinMode(LED_BUILTIN, OUTPUT);
  pinMode(LEDR, OUTPUT);
  pinMode(LEDG, OUTPUT);
  pinMode(LEDB, OUTPUT);

  setLED(0,0,1);

  // set up LED
  byte segmentPins[] = {A0, 2,A7,A3,A2,A1,A6};
  byte numDigits = 9;
  byte digitPins[] = { 3, 4, 5,  // power pins
                      11, 6, 7,  // resistance pins
                      8, 9, 10}; // cadence pins
  bool resistorsOnSegments = true; 
  //bool updateWithDelaysIn = true;
  byte hardwareConfig = COMMON_CATHODE; 
  bool updateWithDelays = false; // Default 'false' is Recommended
  bool leadingZeros = false; // Use 'true' if you'd like to keep the leading zeros
  bool disableDecPoint = true; // Use 'true' if your decimal point doesn't exist or isn't connected. Then, you only need to specify 7 segmentPins[]
  sevseg.begin(hardwareConfig, numDigits, digitPins, segmentPins, resistorsOnSegments, updateWithDelays, leadingZeros, disableDecPoint);
  sevseg.setBrightness(100);

  // initialize the BLE hardware
  if ( !BLE.begin() ) {
    if (DEBUG) Serial.println("starting BLE failed!");
    while (1);
  } else {
    if (DEBUG) Serial.println ("Bluetooth startup succeeded");
  }

  // start scanning for peripherals
  BLE.scanForUuid("1818");

  //BLE.debug(Serial);
}

void loop() {

  setLED(1,0,0); // red
  //delay(100);

  // check if a peripheral has been discovered
  BLEDevice peripheral = BLE.available();

  if (peripheral) {
    setLED(1,1,0); // yellow means peripheral active but not connected yet
    if (DEBUG) Serial.print("Bluetooth connected to ");
    if (DEBUG) Serial.print(peripheral.localName());

    if (peripheral.localName() != "powerMeterService") {
      if (DEBUG) Serial.println("Wrong Local Name. returning.");
      return;
    }

    // stop scanning
    BLE.stopScan();

    if (peripheral.connect()) {
      setLED(0,1,0);
      if (DEBUG) Serial.println (" Bluetooth connected.");

      // discover peripheral attributes
      if (DEBUG) Serial.println("Discovering attributes ...");
      if (peripheral.discoverAttributes()) {
        if (DEBUG) Serial.println("Attributes discovered");
      } else {
        if (DEBUG) Serial.println("Attribute discovery failed!");
        peripheral.disconnect();
        return;
      }

      //int characteristicCount = peripheral.characteristicCount();
      //Serial.print(characteristicCount);
      //Serial.println(" characteristics discovered");

      BLECharacteristic powerChar = peripheral.characteristic("2A63");
      BLECharacteristic resistanceChar = peripheral.characteristic("2AD6");
      BLECharacteristic cadenceChar = peripheral.characteristic("2A5B");

      // subscribe to the powerChar characteristic
      if (DEBUG) Serial.println("Subscribing to powerChar ...");
      if (!powerChar) {
        if (DEBUG) Serial.println("no powerChar found!");
        peripheral.disconnect();
        return;
      } else if (!powerChar.canSubscribe()) {
        if (DEBUG) Serial.println("powerChar is not subscribable!");
        peripheral.disconnect();
        return;
      } else if (!powerChar.subscribe()) {
        if (DEBUG) Serial.println("powerChar subscription failed!");
        peripheral.disconnect();
        return;
      }

      // subscribe to the resistanceChar characteristic
      if (DEBUG) Serial.println("Subscribing to resistanceChar ...");
      if (!resistanceChar) {
        if (DEBUG) Serial.println("no resistanceChar found!");
        peripheral.disconnect();
        return;
      } else if (!resistanceChar.canSubscribe()) {
        if (DEBUG) Serial.println("resistanceChar is not subscribable!");
        peripheral.disconnect();
        return;
      } else if (!resistanceChar.subscribe()) {
        if (DEBUG) Serial.println("resistanceChar subscription failed!");
        peripheral.disconnect();
        return;
      }

      // subscribe to the cadenceChar characteristic
      if (DEBUG) Serial.println("Subscribing to cadenceChar ...");
      if (!cadenceChar) {
        if (DEBUG) Serial.println("no cadenceChar found!");
        peripheral.disconnect();
        return;
      } else if (!cadenceChar.canSubscribe()) {
        if (DEBUG) Serial.println("cadenceChar is not subscribable!");
        peripheral.disconnect();
        return;
      } else if (!cadenceChar.subscribe()) {
        if (DEBUG) Serial.println("cadenceChar subscription failed!");
        peripheral.disconnect();
        return;
      }

      unsigned short power = 68, newPower = 68;
      unsigned char resistance = 69, newResistance = 69;
      unsigned char cadence = 70, newCadence = 70;
      int powerBytesRead = 7, resistanceBytesRead = 8, cadenceBytesRead = 9;

      powerChar.readValue(power);
      resistanceChar.readValue(resistance);
      cadenceChar.readValue(cadence);

      while (peripheral.connected()) {
        setLED(0,0,0);
        if (powerChar.valueUpdated()) {
          powerBytesRead = powerChar.readValue(newPower);
          power = newPower;
        }
        if (resistanceChar.valueUpdated()) {
          resistanceBytesRead = resistanceChar.readValue(newResistance);
          resistance = newResistance;
        }
        if (cadenceChar.valueUpdated()) {
          cadenceBytesRead = cadenceChar.readValue(newCadence);
          cadence = newCadence;
        }

        if (DEBUG) {
          Serial.print(" Bytes read: ");
          Serial.print(powerBytesRead);
          Serial.print(resistanceBytesRead);
          Serial.println(cadenceBytesRead);
        }
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

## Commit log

2020-07-23 Initial upload
    arduino (.ino) and fritz (.fzz) files
    [powermeterCentral.fzz, powermeterPeripheral.fzz]
2020-08-12 bluetooth mostly working now.
    [lefthalf.stl, powermeterDisplay.fzz, powermeterDisplay_prototype1.stl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]
2020-08-12 move hx711 circuit jpb
2020-08-12 move hx711 circuit jpg
2020-08-17 Remove SevenSeg library and use SevSeg instead, which is simpler and does not have dimming issues related to refresh rate
    [powermeterDisplay.ino]
2020-08-17 print 888s when not connected, increase range of prints to int instead of uchar
2020-08-27 display prototype 6
    [powermeterDisplay_prototype6_top.stl]
2020-08-28 add new measurement struct that accumulates samples over fixed time, set to 1000ms to start. add led usage to denote connection status. check in prototype6 case
    [powermeterDisplay_prototype6_top.stl]
2020-09-01 add led status to both units. minor other cleanup. add prototype6 display case.
    [powermeterDisplay_prototype6_top.stl]
2020-11-15 fix power reading to zero
    [powermeterSensor.fzz]
2020-11-15 calibrating the gyro
2020-11-20 somewhat working. still need to calibrate power and resistance.
2020-11-20 commit a bunch of uncommitted files.
    [powermeterDisplay_prototype6_top_left.stl, powermeterDisplay_prototype6_top_right.stl, powermeterDisplay_prototype7_bottoms.stl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]
2020-11-20 power and resistance calibration
2020-11-21 add some calibration to prove that option 1 is the better model.
2020-11-23 change power ble characteristic to a short to allow values >255. make sensor self-calibrate on startup fix resistance equation to not return nans make resistance compute from displayed measurements, 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
    [powermeterDisplay.ino, powermeterSensor.ino]
2020-11-23 add picture of case prototypes
2020-11-26 fix up resistance equations.
2020-12-04 final calibration factors for now.
2020-12-22 Add beginnings of leading zero removal, although it currently messes up timing, so I might need to rewrite the SevSeg library to get it to do what I want.
    Add clear message about MAXNUMDIGITS since I lost several hours to that on a new computer.
2020-12-22 Add beginnings of leading zero removal for https://github.com/jdt23/powermeter/issues/9, although it currently messes up timing, so I might need to rewrite the SevSeg library to get it to do what I w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
    [powermeterDisplay.ino]
2026-03-24 Add iOS bike computer app to replace hardware display
    Replace the Arduino-based 7-segment LED display with an iPhone app that:
    - Connects to the BLE power sensor via CoreBluetooth (same UUID 1818 protocol)
    - Displays power, cadence, resistance in a bike computer UI
    - Streams heart rate from Apple Watch via HealthKit
    - Records workouts with full sample data (power, cadence, HR)
    - Saves completed workouts to Apple Health as cycling activities
    The sensor firmware requires no changes - the iPhone connects as a
    BLE central using the same service/characteristic UUIDs.
    Tech stack: SwiftUI, CoreBluetooth, HealthKit
    Requires: Xcode 15+, iOS 17+, XcodeGen (brew install xcodegen)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
2026-03-26 Fix HealthKit save and add confirmation before saving
    - Don't auto-save to Apple Health on workout end
    - Show "Save to Apple Health" button on summary screen instead
    - Display what will be sent: workout type, sample counts, calories
    - Add proper error handling with retry option if save fails
    - Show saving/saved/failed states with feedback
    - Include start/end dates in WorkoutSummary for accurate save
2026-03-26 Add Apple Watch companion app for live workout tracking
    Watch app features:
    - Starts HKWorkoutSession for continuous heart rate monitoring
    - Shows live power, cadence, resistance, HR, and calories on wrist
    - Streams heart rate back to iPhone (more reliable than HealthKit queries)
    - Workout appears on watch face with green exercise ring credit
    - Auto-saves workout to HealthKit via HKLiveWorkoutBuilder with
    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
2026-03-26 Add app icon: lightning bolt with power gauge
    Green lightning bolt representing power output, overlaid on a
    color-coded gauge arc (green -> yellow -> orange) showing power
    zones with a needle. Dark background.
2026-03-26 Fix BLE scanning, redesign layout and icon
    BLE fix:
    - Remove device name filter from scan - just connect to any peripheral
    advertising UUID 1818 (the Cycling Power Service). iOS often doesn't
    include the local name in advertisement data, causing it to scan
    forever without connecting.
    Layout: instantaneous values large, averages small
    - Power, cadence, HR show live value in large bold text
    - Avg and max values appear as small muted text below each metric
    - More compact spacing to fit everything without scrolling
    Workout summary: fits one screen
    - Compact 2-column grid for stats instead of full-width rows
    - Health data sample counts shown inline
    - No ScrollView needed
    Icon: bigger and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
2026-03-26 Bigger fonts, polished layout, fix HealthKit save
    Display:
    - Use GeometryReader to fill available screen height with metrics
    - Power card scales up to 96pt font, fills full row with gradient bg
    - Cadence/HR/Resistance scale to ~52pt based on available space
    - Minimalist controls: icon-only pause/stop buttons during workout
    - Cleaner card styling with subtle gradient on power card
    HealthKit save fix:
    - Removed cyclingPower and cyclingCadence from write authorization
    and sample creation - these types silently fail on many devices,
    causing the builder chain to hang without calling completion
    - Now saves: workout type, duration, heart rate samples, calories
    - Power/cadence data is saved by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
2026-03-26 Add avg/max to all metrics, fill screen, fix HealthKit save
    Metrics:
    - All cards now show avg and max during workout (cadence, resistance,
    HR, power) instead of only some
    - Track resistance avg/max in WorkoutSession
    - Cards fill entire screen height with no wasted black space
    - Power font scales up to 110pt, other metrics up to 56pt
    - Spacers inside cards center the values vertically
    HealthKit save:
    - Added 10-second timeout so save never hangs forever
    - Clamp sample dates to workout time range
    - Better error messages pointing user to Settings
    - Thread-safe completion handler (prevents double-callback)
2026-03-26 Fix frame() call incompatible with older Xcode
2026-03-26 Fill entire screen, save power+cadence to Apple Health
    Layout:
    - Use .ignoresSafeArea() to truly fill edge to edge
    - Calculate row heights from total screen height including safe areas
    - Remove all extra padding/gaps that were causing blank space
    - Power font scales to 120pt, others to 64pt
    HealthKit:
    - Add cycling power and cadence samples back to workout save
    - Best-effort: if power/cadence types aren't available on device,
    gracefully falls back to saving just HR and calories
    - If full sample add fails, retries with energy-only before finishing
    - All sample dates clamped to workout time range
2026-03-26 Add speed, distance, power zones, NP, IF, and TSS
    New computed metrics:
    - Speed (mph) from Peloton formula: (cadence-35)^0.4 * (resistance/100) * 9 + 0.4
    - Distance accumulated from speed over time
    - Power zones (Z1-Z6) based on configurable FTP (default 200W):
    Z1 Recovery, Z2 Endurance, Z3 Tempo, Z4 Threshold, Z5 VO2Max, Z6 Anaerobic
    - Normalized Power: 30-second rolling average raised to 4th power
    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
2026-03-26 Add swipeable pages, settings screen, fix Watch provisioning
    Swipeable pages during workout:
    - Page 1 (main): Power with zone, Cadence, Resistance, HR, Calories
    - Page 2 (swipe left): Speed, Distance, NP, IF, TSS, Zone, Avg/Max Power
    - Page dots in status bar show which page you're on
    - When idle, only page 1 is shown
    Settings screen (gear icon when idle):
    - Configurable FTP (default 200W), persisted with @AppStorage
    - Shows computed power zone ranges based on FTP
    - Shows sensor info
    Fix Watch provisioning error:
    - Removed com.apple.developer.healthkit.access (Verifiable Health
    Records) from both Watch and iPhone entitlements — this capability
    requires a paid developer account. Basic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
2026-03-26 Move speed/distance to page 1, tighten layout
    Page 1 (main): 4 rows edge-to-edge
    - Power (with zone badge)
    - Cadence | Resistance
    - Heart Rate | Speed
    - Distance | Calories
    Page 2 (swipe): 2 rows, big cells
    - Normalized Power | Intensity Factor
    - Training Stress | Zone
    - Removed redundant avg/max power (already on page 1)
    Layout: reduced all gaps to 2px, padding to 2px, status bar
    to 28px, controls to 48px. Disabled TabView page indicator
    dots (custom dots in status bar instead) to reclaim space.
2026-03-26 Replace TabView with custom swipe, fill full screen
    The TabView .page style adds ~10% internal padding that cannot
    be overridden. Replaced with a custom DragGesture-based page
    swipe that gives full control over layout — zero wasted space.
    - Cards now fill from the very top to the very bottom of the screen
    - Status bar: 26px, controls: 46px, everything else is metrics
    - All gaps reduced to 2px, all padding reduced to minimum
    - All metrics show avg and max during workout (cadence, resistance,
    HR, speed all have avg/max)
    - Swipe left/right with 60px threshold and spring animation
2026-03-26 Fix Watch app embedding — iPhone app embeds Watch, not vice versa
    The Watch app wasn't appearing because the dependency was backwards.
    The iPhone app must depend on and embed the Watch app (not the other
    way around). Moved the dependency from PowerMeterWatch -> PowerMeterApp
    to PowerMeterApp -> PowerMeterWatch.
2026-03-26 Fix full-screen: add safe area insets to size and offset content up
    GeometryReader.ignoresSafeArea() expands the frame but geo.size
    still reports the safe-area-adjusted size. Fix: add
    geo.safeAreaInsets.top + bottom to get true full height, then
    offset the content up by -topInset so it starts at pixel 0.
2026-03-26 Use UIKit APIs for screen size and position content with .position()
    SwiftUI's GeometryReader reports zero safe area insets when
    .ignoresSafeArea() is applied, making it impossible to calculate
    the true screen size from SwiftUI alone.
    New approach:
    - UIScreen.main.bounds for exact screen dimensions
    - UIWindowScene safeAreaInsets from UIKit for real inset values
    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
2026-03-26 Rewrite layout: flexible rows instead of manual height calculations
    Root cause of the vertical space issue: manually calculating heights
    from UIScreen.main.bounds or GeometryReader caused mismatches with
    the actual available space, leading to oversized/undersized content.
    New approach: NO manual height calculations at all.
    - Every row uses .frame(maxWidth: .infinity, maxHeight: .infinity)
    - SwiftUI divides the space equally among flexible rows
    - Only the status bar (28pt) and controls (44pt) have fixed heights
    - GeometryReader is only used for the swipe page width
    - .background(Color.black.ignoresSafeArea()) extends black behind
    the Dynamic Island and home indicator areas
    Removed: FullSc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
2026-03-26 Completely rewrite layout: simplest possible approach
    Stripped everything back to basics:
    - No GeometryReader anywhere
    - No UIScreen.main.bounds
    - No manual height calculations
    - No UIViewControllerRepresentable
    - No safe area hacks
    Just a VStack where:
    - Status bar: .frame(height: 28) fixed
    - Controls: .frame(height: 44) fixed
    - Main metrics: .frame(maxWidth: .infinity, maxHeight: .infinity)
    which tells SwiftUI to fill ALL remaining space
    Each tile is a ZStack with Spacers that expand to fill offered space.
    The outer VStack distributes space: fixed items get their height,
    the flexible middle section gets everything else.
    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
2026-03-27 Fix frame() calls: split width and maxHeight into separate calls
2026-03-27 Redesign Watch display: all key metrics on one screen
    Main screen (no scrolling needed):
    - Duration at top
    - Power large and bold (36pt)
    - HR | Cadence side by side
    - Speed | Distance side by side
    - Calories | Resistance side by side
    - PAUSED indicator when paused
    Detail screen (swipe down via vertical TabView):
    - All metrics in a labeled list format
    Also sends speed, distance, and calories from iPhone to Watch
    via WatchConnectivity so all metrics are available on both devices.
2026-03-27 Watch: bigger fonts, fill screen, ignoresSafeArea
    - Power: 48pt (was 36pt)
    - Metric tiles: 24pt (was 18pt), use .frame(maxHeight: .infinity)
    so tiles expand to fill available vertical space
    - Duration: 18pt (was 16pt)
    - Added .ignoresSafeArea() to TabView
    - Added .frame(maxWidth: .infinity, maxHeight: .infinity) to both
    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
2026-03-27 Major update: HR zones, swipe pages, dedup saves, full-screen fix
    Full-screen (iOS 26 workaround):
    - Custom FullScreenHostingController overrides viewSafeAreaInsetsDidChange
    to negate safe area insets dynamically. This works around the iOS 26
    regression where safeAreaRegions=[] is ignored.
    - Also overrides prefersStatusBarHidden, prefersHomeIndicatorAutoHidden,
    preferredScreenEdgesDeferringSystemGestures
    - Removed hardcoded 59pt/34pt spacers
    Heart rate zones (replaces power zones on main screen):
    - Z1 Recovery (<60%), Z2 Fat Burn (60-70%), Z3 Cardio (70-80%),
    Z4 Hard (80-90%), Z5 Peak (>90%) based on configurable max HR
    - HR is now the hero card on page 1, power is in row 2
    - Max HR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
2026-03-27 Make sensor compatible with native Apple Watch Workout app
    The standard Cycling Power Measurement (0x2A63) format requires:
    - Bytes 0-1: Flags (uint16, 0x0000 = no optional fields)
    - Bytes 2-3: Instantaneous Power (sint16, little-endian)
    Previously the sensor wrote just 2 bytes (raw power), so the Watch
    interpreted power as flags and got no power data.
    Sensor changes:
    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
2026-03-27 Fix vertical space: add explicit height to GeometryReader content
    The actual bug was that the HStack inside the GeometryReader (used
    for swipeable pages) had no explicit height. The pages inside had
    .frame(maxHeight: .infinity) but without the HStack knowing the
    GeometryReader's height, they sized to intrinsic content instead
    of filling the space.
    Fix: .frame(width: w, height: h) on each page AND .frame(height: h)
    on the HStack, using geo.size.height from the GeometryReader.
    Also reverted to SwiftUI App protocol — the UIKit lifecycle with
    FullScreenHostingController added complexity without solving the
    actual issue (which was the GeometryReader content height, not
    safe areas). Removed UI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
2026-03-27 Fix vertical space: explicit row heights from GeometryReader
    Root cause: VStack children (ZStacks, HStacks) had no explicit height.
    SwiftUI sized them to their text content (~80pt each) instead of
    distributing the available space evenly. .frame(maxHeight: .infinity)
    on the outer VStack only made the container accept space — it did NOT
    redistribute that space to children.
    Fix: pass GeometryReader height into mainPage(h:) and detailPage(h:),
    calculate rowH = (h - gaps) / numberOfRows, and set .frame(height: rowH)
    on every row. Each row now gets exactly 1/4 of the available space
    (for 4 rows). This is deterministic — no reliance on SwiftUI's
    flexible layout distribution.
    Also reverted to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
2026-03-27 Add UILaunchScreen to Info.plist — fixes full-screen on all devices
    THE ROOT CAUSE: Without a UILaunchScreen key in Info.plist, iOS
    runs the app in compatibility mode with a smaller window sized for
    older iPhones. This is why the content AND system dialogs were all
    constrained to a smaller area — the window itself was not full screen.
    The fix is one key: UILaunchScreen as an empty dict tells iOS this
    app supports the native screen size of whatever device it runs on.
